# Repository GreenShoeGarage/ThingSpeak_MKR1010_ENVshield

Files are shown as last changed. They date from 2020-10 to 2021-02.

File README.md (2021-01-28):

View this project on [CADLAB.io](https://cadlab.io/project/23807). 

# Workspace Health Monitoring Gadget

[https://greenshoegarage.com/2020/10/learning-from-covid-19/](https://greenshoegarage.com/2020/10/learning-from-covid-19/)

## Goal

An open-source device that can monitor 8+ key environmental factors that affect people's perception of a healthy and productive workspace:

* Temperature
* Pressure
* eCO2
* Humidity
* Brightness
* Noise
* TVOC
* PM 2.5um

### Code and hardware is a prototype, no guarentee of any sort is implied. Use at your own risk.

## Functionality

1. Monitor 8 environmental factors
   1. Central processing of all sensor data
2. Record the telemetry locally
   1. 24-hour rolling log
   2. Store on microSD card
3. Display the telemetry locally
   1. Display new data point every 3 seconds
4. Transmit telemetry to web-based cloud service
   1. Send latest sensor readings every 10 minutes

## Bill of Materials

| Supplier | Product ID | Quantity | Description | Unit Price | Function | 
| :--- | :--- | :--- | :--- | :--- | :--- |
| Mouser | 782-ABX00023 | 1 | MKR1010 | $32.10 | Processing and Comms | 
| Mouser | 782-ASX00011 | 1 | MKR ENV Shield | $34.40 | Temp, UVA/UVB/UV Index, Humidity, Pressure, Lux |
| Adafruit | 3709 | 1 | SGP30 Air Quality Sensor Breakout | $19.95 | VOC, eCO2 | 
| Adafruit | 4632 | 1 | PMSA003I Air Quality Breakout | $44.95 | Particulate Matter | 
| Adafruit | 421 | 1 | I2S MEMS Microphone Breakout SPH0645LM4H | $6.95 | Noise | 

Get the PCB from OSHPark: [https://oshpark.com/shared\_projects/NU4I8Xzd](https://oshpark.com/shared_projects/NU4I8Xzd)

PartsBox Project BOM: [https://partsbox.com/mbparks/project/1s51nh9teghyx9e4by3gwn3nxp/](https://partsbox.com/mbparks/project/1s51nh9teghyx9e4by3gwn3nxp/)

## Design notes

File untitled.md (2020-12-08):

# Workspace Health Monitoring Gadget Wiki

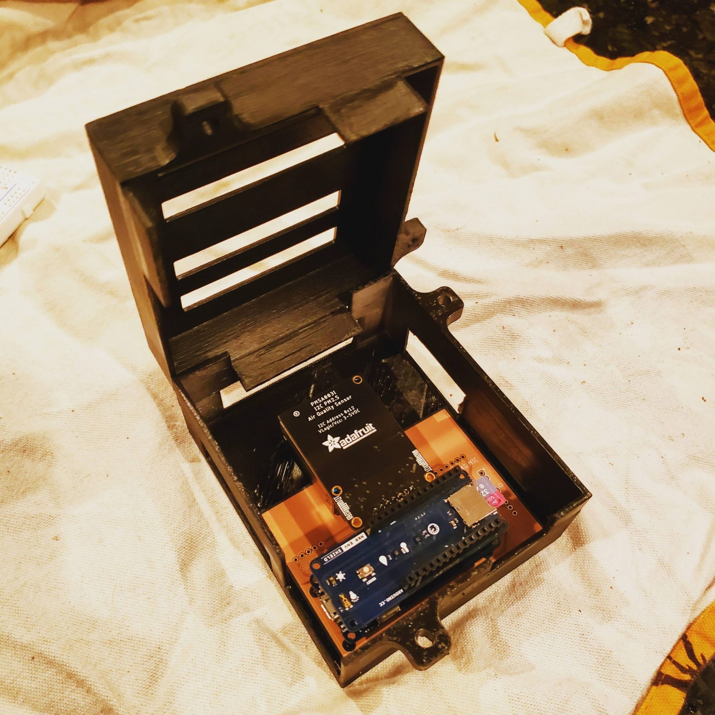
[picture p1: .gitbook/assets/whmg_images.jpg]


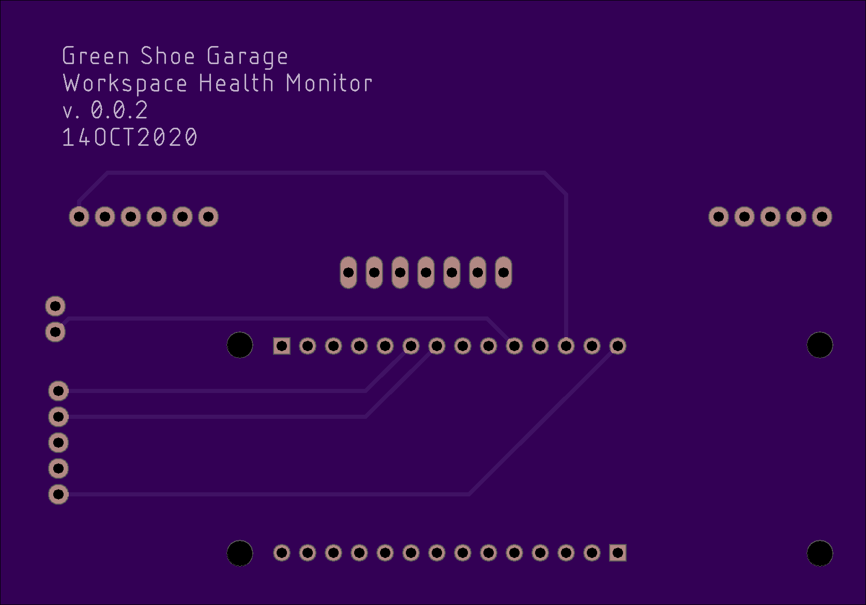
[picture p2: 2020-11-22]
Documentation/Images/OSHPark_PCB_Bottom.png

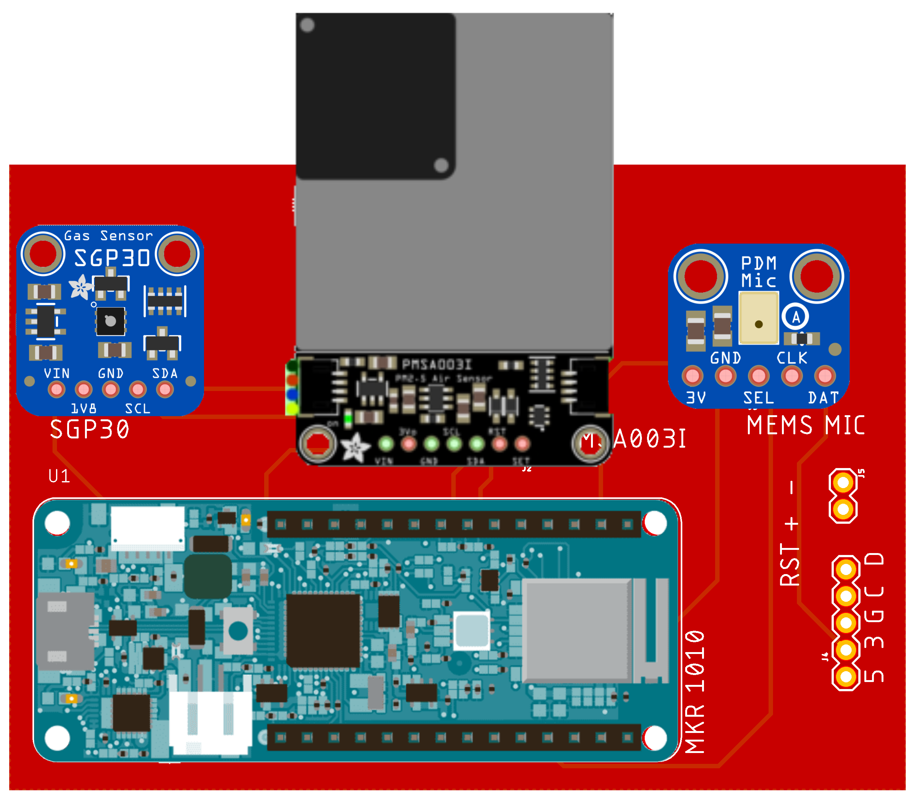
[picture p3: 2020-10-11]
Documentation/Images/WorkspaceHealthMonitor_v002_PCBA.png

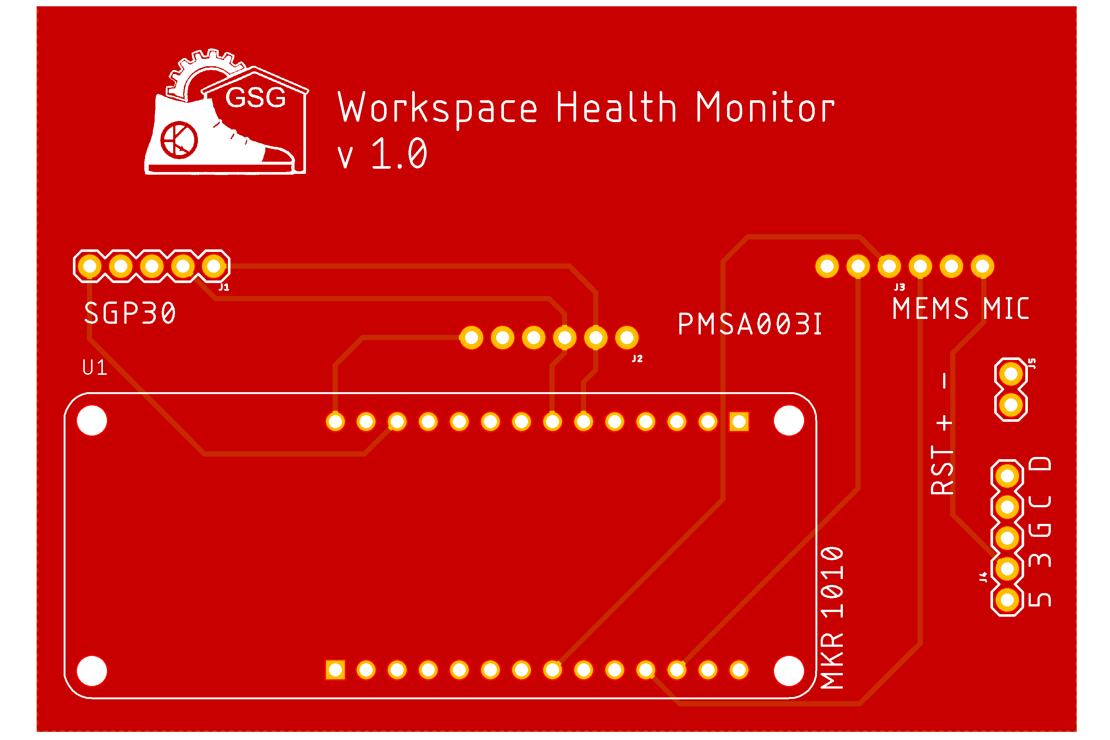
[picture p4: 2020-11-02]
Documentation/Images/WorkspaceHealthMonitor_v001_PCB.png

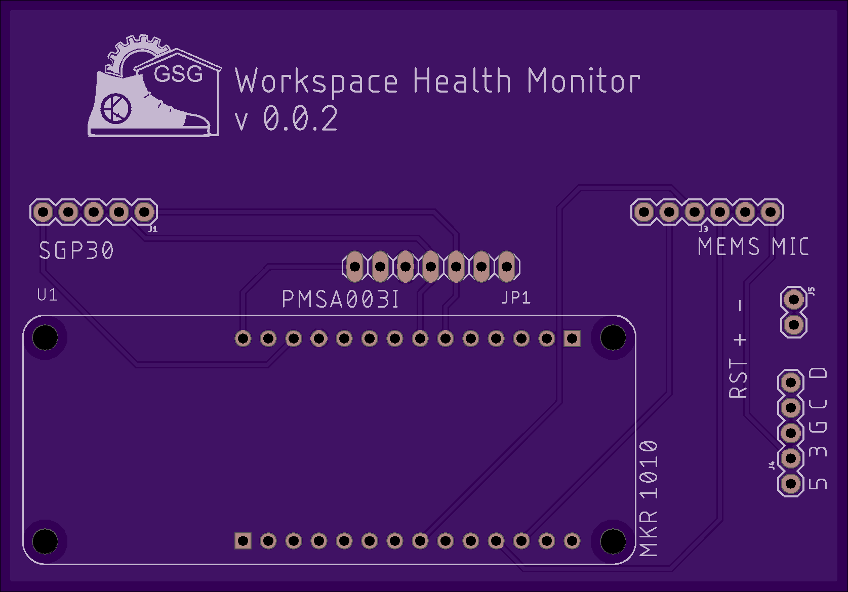
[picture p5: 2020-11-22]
Documentation/Images/OSHPark_PCB_Top.png

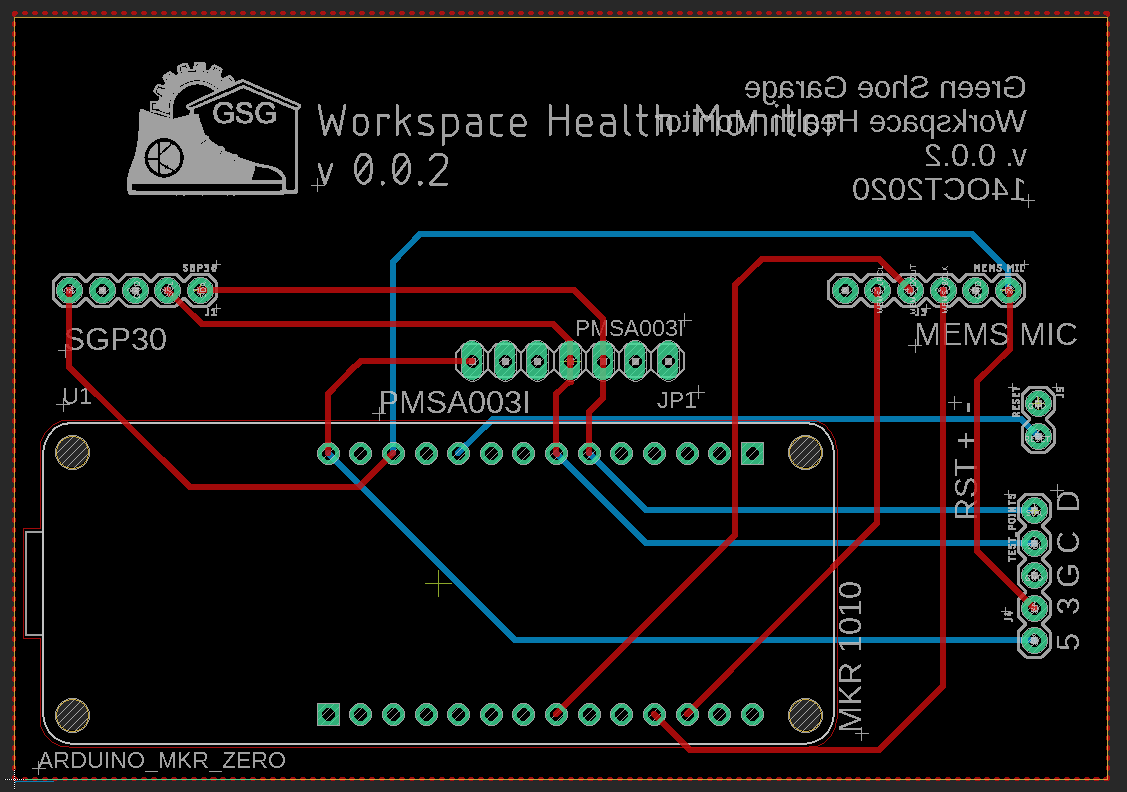
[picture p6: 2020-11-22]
Documentation/Images/WorkspaceHealthMonitor_BRD.png

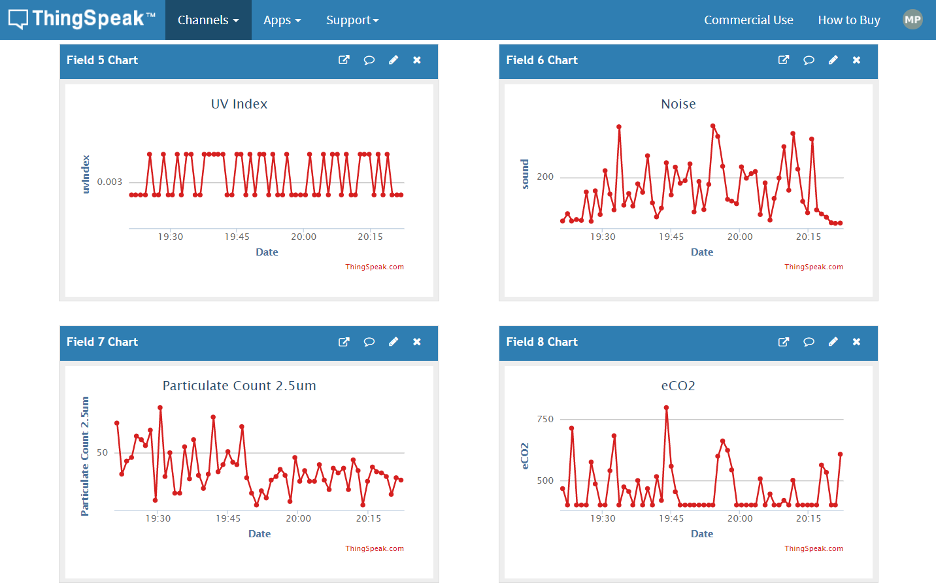
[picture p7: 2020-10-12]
Documentation/Images/ThingSpeak_Metrics02.png

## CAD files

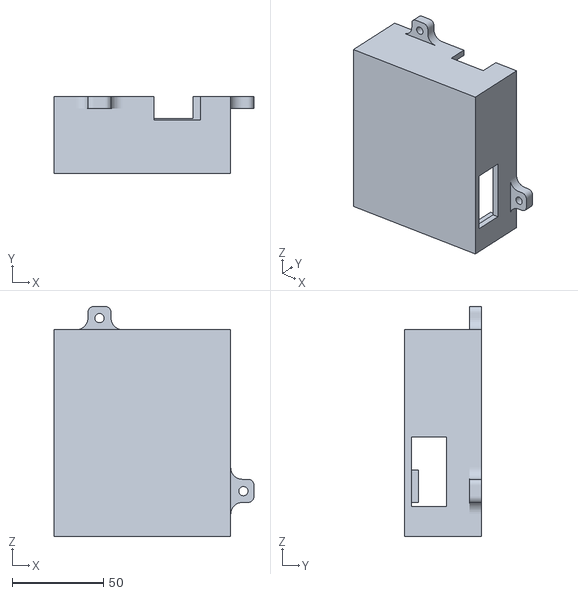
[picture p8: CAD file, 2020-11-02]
3D/Bottom_ThickWalls.stl
109.5 x 41.9 x 126.0

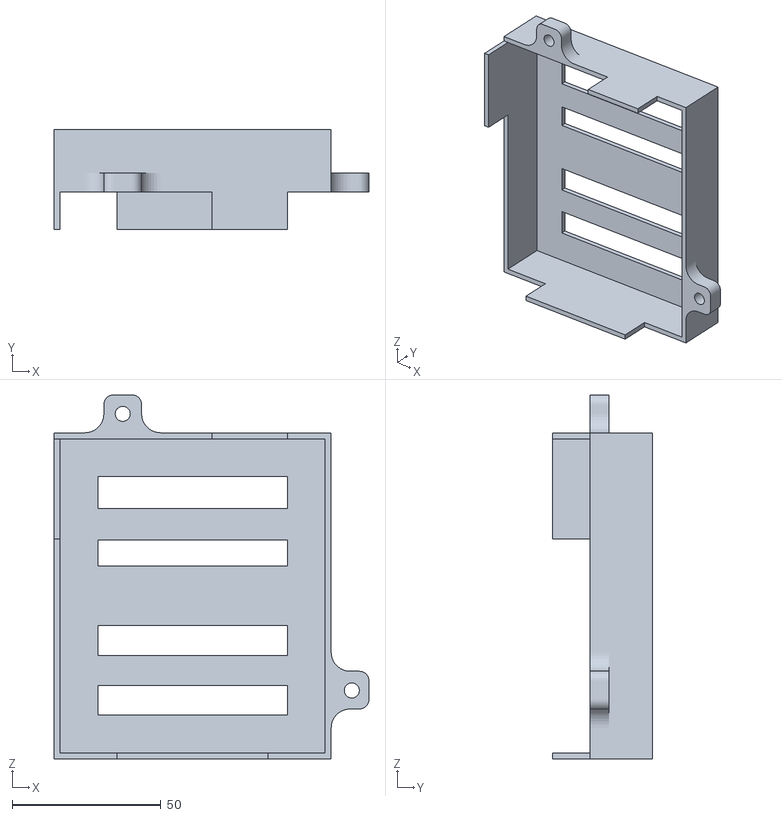
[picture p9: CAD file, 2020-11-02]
3D/Top.stl
105.9 x 33.8 x 122.4

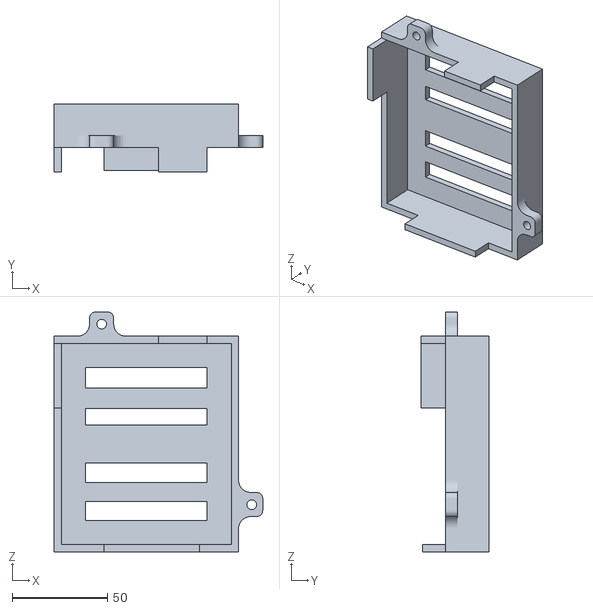
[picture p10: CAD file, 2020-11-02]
3D/Top_ThickWalls.stl
109.5 x 35.6 x 126.0

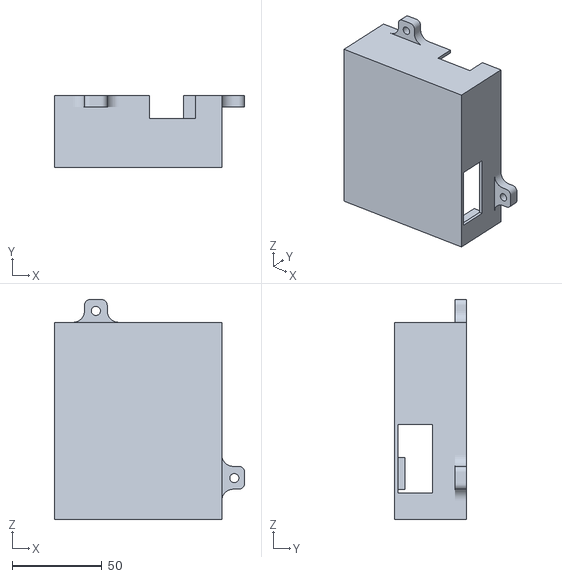
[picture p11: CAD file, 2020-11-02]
3D/Bottom.stl
105.9 x 40.1 x 122.4

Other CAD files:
3D/Bottom.obj
3D/Top.obj

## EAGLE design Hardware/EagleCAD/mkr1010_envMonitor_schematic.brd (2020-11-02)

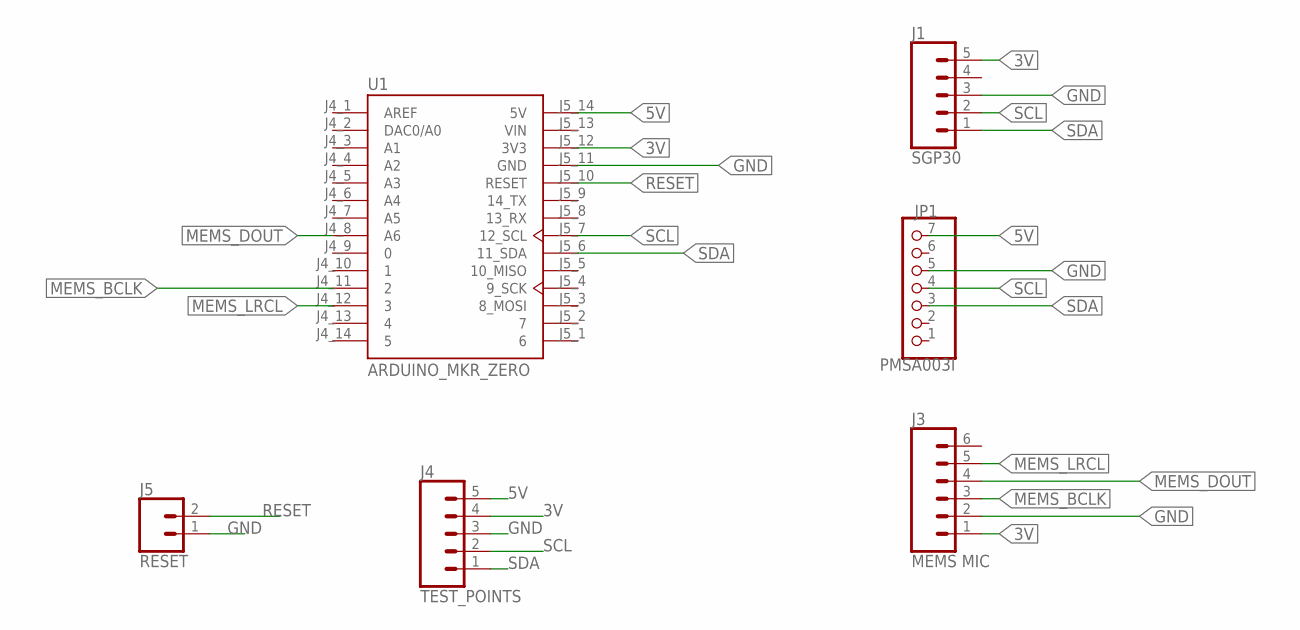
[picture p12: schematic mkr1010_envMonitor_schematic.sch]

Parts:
J1: SGP30; 1X05
J3: MEMS MIC; 1X06
J4: TEST_POINTS; 1X05
J5: RESET; 1X02
JP1: PMSA003I; 1X07
U1: ARDUINO_MKR_ZERO; MODULE_ARDUINO_MKR_ZERO

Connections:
3V: J1.5, J3.1, J4.4, U1.J5_12 (3V3)
5V: J4.5, JP1.7, U1.J5_14 (5V)
GND: J1.3, J3.2, J4.3, J5.1, JP1.5, U1.J5_11 (GND)
MEMS_BCLK: J3.3, U1.J4_11 (2)
MEMS_DOUT: J3.4, U1.J4_8 (A6)
MEMS_LRCL: J3.5, U1.J4_12 (3)
RESET: J5.2, U1.J5_10 (RESET)
SCL: J1.2, J4.2, JP1.4, U1.J5_7 (12_SCL)
SDA: J1.1, J4.1, JP1.3, U1.J5_6 (11_SDA)
VIN: U1.J5_13 (VIN)

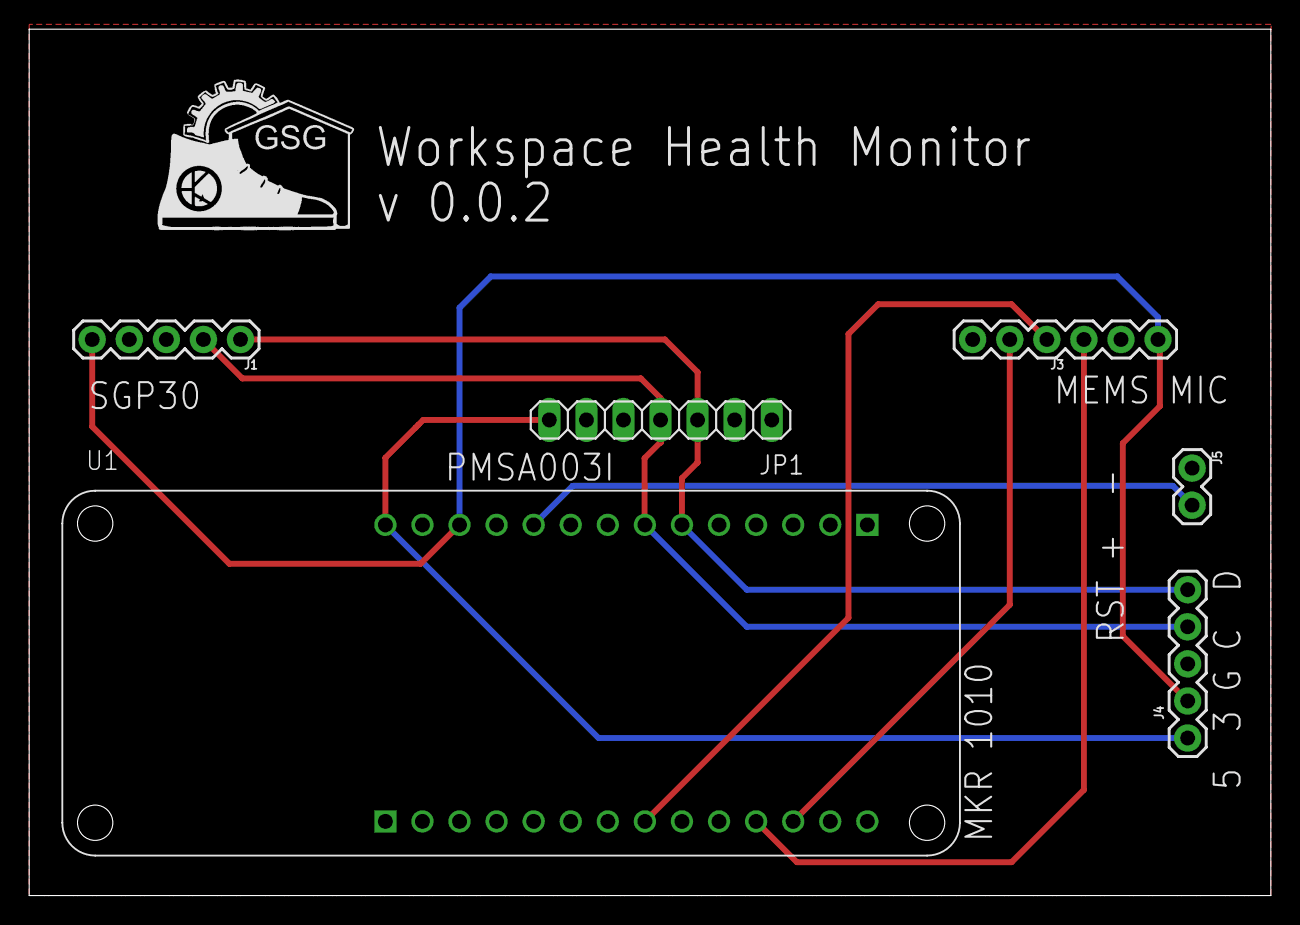
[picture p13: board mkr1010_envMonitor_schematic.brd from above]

Board: 2 copper layers, 85.1 x 59.4 mm, 6 parts (0 on the bottom side), 9 nets.

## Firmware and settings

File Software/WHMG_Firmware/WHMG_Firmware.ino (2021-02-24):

/*
  WriteMultipleFields

  Description: Writes values to fields 1,2,3,4 and status in a single ThingSpeak update every 20 seconds.

  Hardware: Arduino MKR WiFi 1010

  !!! IMPORTANT - Modify the secrets.h file for this project with your network connection and ThingSpeak channel details. !!!

  Note:
  - Requires WiFiNINA library
  - This example is written for a network using WPA encryption. For WEP or WPA, change the WiFi.begin() call accordingly.

  ThingSpeak ( https://www.thingspeak.com ) is an analytic IoT platform service that allows you to aggregate, visualize, and
  analyze live data streams in the cloud. Visit https://www.thingspeak.com to sign up for a free account and create a channel.

  Documentation for the ThingSpeak Communication Library for Arduino is in the README.md folder where the library was installed.
  See https://www.mathworks.com/help/thingspeak/index.html for the full ThingSpeak documentation.

  For licensing information, see the accompanying license file.

  Copyright 2018, The MathWorks, Inc.

  Microphone Connections (Adafruit I2S MEMS Microphone Breakout SPH0645LM4H)
    GND connected GND
    3.3V connected 3.3V (Feather, Zero) or VCC (MKR1000, MKRZero)
    LRCLK / WS connected to pin 0 (Feather, Zero) or pin 3 (MKR1000, MKRZero)
    BCLK connected to pin 1 (Feather, Zero) or pin 2 (MKR1000, MKRZero)
    DOUT connected to pin 9 (Zero) or pin A6 (MKR1000, MKRZero
    SEL N/C

  Adafruit PM2.5 sensor (MSA003I Air Quality Breakout (PM0.3-100um))
    I2C address 0x12 (cannot be changed)
    3.3V
    SDA, SCL, 3V, GND

  SGP30 Air Quality Sensor Breakout (TVOC and eCO2)
    The sensor uses I2C address 0x58
    Since the sensor chip uses 3 VDC for logic, we have included a voltage regulator on board that will take 3-5VDC and safely convert it down
    SDA, SCL, 3.3V or 5V, GND

*/

#include <SPI.h>
#include <SD.h>
#include <WiFiNINA.h>
#include <Arduino_MKRENV.h>
#include <I2S.h>
#include <ArduinoLowPower.h>
#include "ThingSpeak.h"
#include "secrets.h"
#include "Adafruit_PM25AQI.h"
#include <utility/wifi_drv.h>
#include "Adafruit_SGP30.h"



#define SAMPLES 128
#define CSPIN 4
#define GREEN_LED 25
#define RED_LED 26
#define BLUE_LED 27


float sensor_temperature_reading = 0.0;
float sensor_humidity_reading    = 0.0;
float sensor_pressure_reading    = 0.0;
float sensor_illuminance_reading = 0.0;
float sensor_uva_reading         = 0.0;
float sensor_uvb_reading         = 0.0;
float sensor_uvIndex_reading     = 0.0;
float sensor_noiseLevel_reading  = 0.0;

int sensor_partcount_03um_reading  = 0;
int sensor_partcount_05um_reading  = 0;
int sensor_partcount_10um_reading  = 0;
int sensor_partcount_25um_reading  = 0;
int sensor_partcount_50um_reading  = 0;
int sensor_partcount_100um_reading = 0;

uint16_t sensor_tvoc_reading = 0;
uint16_t sensor_eco2_reading = 0;

Adafruit_PM25AQI aqi = Adafruit_PM25AQI();
PM25_AQI_Data aqiData;

Adafruit_SGP30 sgp;

unsigned long lastSDWriteTime = 0;
const unsigned long SDwriteDelay = 5000;

unsigned long lastTransmitTime = 0;
const unsigned long transmitDelay = 5000;

char ssid[] = SECRET_SSID;   // your network SSID (name)
char pass[] = SECRET_PASS;   // your network password
WiFiClient  client;

unsigned long myChannelNumber = SECRET_CH_ID;
const char * myWriteAPIKey = SECRET_WRITE_APIKEY;

const char* FILENAME = "telemetr.csv";
File myFile;






//////////////////////////////////////////////////////////////////////////
void setup() {
  WiFiDrv::pinMode(GREEN_LED, OUTPUT);  //GREEN
  WiFiDrv::pinMode(RED_LED, OUTPUT);  //RED
  WiFiDrv::pinMode(BLUE_LED, OUTPUT);  //BLUE
  WiFiDrv::digitalWrite(GREEN_LED, HIGH); // for full brightness
  WiFiDrv::digitalWrite(RED_LED, LOW); // for full brightness
  WiFiDrv::digitalWrite(BLUE_LED, LOW); // for full brightness

  Serial.begin(115200);  // Initialize serial
  while (!Serial) {
    blinkLedError();
  }

  Serial.print("Initializing MKR ENV shield...");
  if (!ENV.begin()) {
    Serial.println("FAILED to initialize MKR ENV shield!");
    while (true) {
      blinkLedError();
    }
  }
  Serial.println("MKR ENV shield successfully initialized");


  Serial.print("Initializing I2S microphone...");
  if (!I2S.begin(I2S_PHILIPS_MODE, 16000, 32)) {
    Serial.println("FAILED to initialize I2S microphone!");
    while (true) {
      blinkLedError();
    }
  }
  Serial.println("I2S microphone successfully initialized");


  Serial.print("Initializing PM 2.5 AQI Sensor...");
  if (! aqi.begin_I2C()) {      // connect to the sensor over I2C
    Serial.println("Could not find PM 2.5 sensor!");
    while (true) {
      blinkLedError();
    }
  }
  Serial.println("PM 2.5 AQI sensor successfully initialized!");


  Serial.print("Initializing SGP30 sensor...");
  if (! sgp.begin()) {
    Serial.println("Sensor not found :(");
    while (1);
  }
  Serial.println("SGP30 sensor successfully initialized!");


  Serial.print("Initializing WiFi module...");
  if (WiFi.status() == WL_NO_MODULE) {
    Serial.println("Communication with WiFi module failed!");
    while (true) {
      blinkLedError();
    }
  }
  String fv = WiFi.firmwareVersion();
  Serial.print("Wifi Firmware Version: ");
  Serial.println(fv);
  Serial.println("WiFi successfully initialized");


  Serial.print("Initializing SD card...");
  if (!SD.begin(CSPIN))
  {
    Serial.println("initialization failed!");
    while (true) {
      blinkLedError();
    }
  }
  Serial.println("SD card successfully initialized.");

  ThingSpeak.begin(client);  //Initialize ThingSpeak
}




///////////////////////////////////////////////////////////////////////////////////////////////
void loop() {
  readSensors();
  printTelemetry();
  sendToThingspeak();
  writeTelemetrySD();
  delay(2000);
}




///////////////////////////////////////////////////////////////////////////////////////////////
void readSensors() {
  readMKR();
  readNoiseSensor();
  readAQI();
  readSGP();
}



///////////////////////////////////////////////////////////////////////////////////////////////
void readMKR() {
  sensor_temperature_reading = ENV.readTemperature();
  sensor_humidity_reading    = ENV.readHumidity();
  sensor_pressure_reading    = ENV.readPressure();
  sensor_illuminance_reading = ENV.readIlluminance();
  sensor_uva_reading         = ENV.readUVA();
  sensor_uvb_reading         = ENV.readUVB();
  sensor_uvIndex_reading     = ENV.readUVIndex();
}




///////////////////////////////////////////////////////////////////////////////////////////////
void readNoiseSensor() {
  int samples[SAMPLES];

  for (int i = 0; i < SAMPLES; i++) {
    int sample = 0;
    while ((sample == 0) || (sample == -1) ) {
      sample = I2S.read();
    }
    // convert to 18 bit signed
    sample >>= 14;
    samples[i] = sample;
  }

  // ok we hvae the samples, get the mean (avg)
  float meanval = 0;
  for (int i = 0; i < SAMPLES; i++) {
    meanval += samples[i];
  }
  meanval /= SAMPLES;

  // subtract it from all sapmles to get a 'normalized' output
  for (int i = 0; i < SAMPLES; i++) {
    samples[i] -= meanval;
  }

  // find the 'peak to peak' max
  float maxsample, minsample;
  minsample = 100000;
  maxsample = -100000;
  for (int i = 0; i < SAMPLES; i++) {
    minsample = min(minsample, samples[i]);
    maxsample = max(maxsample, samples[i]);
  }
  sensor_noiseLevel_reading = maxsample - minsample;
}





///////////////////////////////////////////////////////////////////////////////////////////////
void readAQI() {
  if (! aqi.read(&aqiData)) {
    Serial.println("Could not read from AQI");
    delay(500);  // try again in a bit!
    return;
  }
  //Serial.println("AQI reading success");

  sensor_partcount_03um_reading = aqiData.particles_03um;
  sensor_partcount_05um_reading = aqiData.particles_05um;
  sensor_partcount_10um_reading = aqiData.particles_10um;
  sensor_partcount_25um_reading = aqiData.particles_25um;
  sensor_partcount_50um_reading = aqiData.particles_50um;
  sensor_partcount_100um_reading = aqiData.particles_100um;
}





///////////////////////////////////////////////////////////////////////////////////////////////
void readSGP() {
  static int counter = 0;

  if (! sgp.IAQmeasure()) {
    Serial.println("Measurement failed");
    return;
  }
  //Serial.print("TVOC "); Serial.print(sgp.TVOC); Serial.print(" ppb\t");
  //Serial.print("eCO2 "); Serial.print(sgp.eCO2); Serial.println(" ppm");

  if (! sgp.IAQmeasureRaw()) {
    Serial.println("Raw Measurement failed");
    return;
  }
  //Serial.print("Raw H2 "); Serial.print(sgp.rawH2); Serial.print(" \t");
  //Serial.print("Raw Ethanol "); Serial.print(sgp.rawEthanol); Serial.println("");

  delay(1000);

  counter++;
  if (counter == 30) {
    counter = 0;

    uint16_t TVOC_base, eCO2_base;
    if (! sgp.getIAQBaseline(&eCO2_base, &TVOC_base)) {
      Serial.println("Failed to get baseline readings");
      return;
    }
    //Serial.print("****Baseline values: eCO2: 0x"); Serial.print(eCO2_base, HEX);
    //Serial.print(" & TVOC: 0x"); Serial.println(TVOC_base, HEX);
  }

  sensor_tvoc_reading = sgp.TVOC;
  sensor_eco2_reading = sgp.eCO2;

}




///////////////////////////////////////////////////////////////////////////////////////////////
void printTelemetry() {
  Serial.println(F("------------------------------------------------------------"));
  Serial.print(F("Time (ms) since last reboot: "));
  Serial.println(millis());
  Serial.println();

  Serial.print(F(">> Environmental Conditions: "));
  Serial.println();
  Serial.print(F("Temperature (C): "));
  Serial.println(sensor_temperature_reading);
  Serial.print(F("Humidity (%): "));
  Serial.println(sensor_humidity_reading);
  Serial.print(F("Atmosphere Pressure (kPa): "));
  Serial.println(sensor_pressure_reading);
  Serial.print(F("Illuminance (Lux): "));
  Serial.println(sensor_illuminance_reading);
  Serial.print(F("UVA: "));
  Serial.println(sensor_uva_reading);
  Serial.print(F("UVB: "));
  Serial.println(sensor_uvb_reading);
  Serial.print(F("UV Index: "));
  Serial.println(sensor_uvIndex_reading);
  Serial.println();

  Serial.print(F(">> Noise Level: "));
  Serial.println(sensor_noiseLevel_reading);
  Serial.println();

  Serial.println(F(">> Air Quality: Particulate Matter"));
  Serial.println(F("Concentration Units (standard)"));
  Serial.print(F("PM 1.0: ")); Serial.print(aqiData.pm10_standard);
  Serial.print(F("\t\tPM 2.5: ")); Serial.print(aqiData.pm25_standard);
  Serial.print(F("\t\tPM 10: ")); Serial.println(aqiData.pm100_standard);
  Serial.println(F("-----"));
  Serial.println(F("Concentration Units (environmental)"));
  Serial.print(F("PM 1.0: ")); Serial.print(aqiData.pm10_env);
  Serial.print(F("\t\tPM 2.5: ")); Serial.print(aqiData.pm25_env);
  Serial.print(F("\t\tPM 10: ")); Serial.println(aqiData.pm100_env);
  Serial.println(F("-----"));
  Serial.print(F("Particles > 0.3um / 0.1L air:")); Serial.println(sensor_partcount_03um_reading);
  Serial.print(F("Particles > 0.5um / 0.1L air:")); Serial.println(sensor_partcount_05um_reading);
  Serial.print(F("Particles > 1.0um / 0.1L air:")); Serial.println(sensor_partcount_10um_reading);
  Serial.print(F("Particles > 2.5um / 0.1L air:")); Serial.println(sensor_partcount_25um_reading);
  Serial.print(F("Particles > 5.0um / 0.1L air:")); Serial.println(sensor_partcount_50um_reading);
  Serial.print(F("Particles > 50 um / 0.1L air:")); Serial.println(sensor_partcount_100um_reading);
  Serial.println();

  Serial.println(F(">> Air Quality: eCO2 and TVOC"));
  Serial.print(F("eCO2: "));
  Serial.println(sensor_eco2_reading);
  Serial.print(F("TVOC: "));
  Serial.println(sensor_tvoc_reading);
  Serial.println();
  Serial.println(F("------------------------------------------------------------"));

  for (int x = 0; x < 3; x++) {
    Serial.println();
  }

}



///////////////////////////////////////////////////////////////////////////////////////////////
void sendToThingspeak() {
  // Connect or reconnect to WiFi
  if ((millis() - lastTransmitTime) > transmitDelay) {
    if (WiFi.status() != WL_CONNECTED) {
      Serial.print("Attempting to connect to SSID: ");
      Serial.println(SECRET_SSID);
      while (WiFi.status() != WL_CONNECTED) {
        WiFi.begin(ssid, pass); // Connect to WPA/WPA2 network. Change this line if using open or WEP network
        Serial.print(".");
        delay(5000);
      }
      Serial.println("\nConnected.");
    }

    // set the fields with the values
    ThingSpeak.setField(1, sensor_temperature_reading);
    ThingSpeak.setField(2, sensor_humidity_reading);
    ThingSpeak.setField(3, sensor_pressure_reading);
    ThingSpeak.setField(4, sensor_illuminance_reading);
    ThingSpeak.setField(5, sensor_tvoc_reading);
    ThingSpeak.setField(6, sensor_noiseLevel_reading);
    ThingSpeak.setField(7, sensor_partcount_25um_reading);
    ThingSpeak.setField(8, sensor_eco2_reading);

    // write to the ThingSpeak channel
    int x = ThingSpeak.writeFields(myChannelNumber, myWriteAPIKey);
    if (x == 200) {
      Serial.println("Telemetry upload to ThingSpeak successful.");
    }
    else {
      Serial.println("Problem updating channel. HTTP error code " + String(x));
    }
    lastTransmitTime = millis();
  }
}








///////////////////////////////////////////////////////////////////////////////////////////////
void writeTelemetrySD() {
  noInterrupts();
  if ((millis() - lastSDWriteTime) > SDwriteDelay) {
    myFile = SD.open(FILENAME, FILE_WRITE);
    if (myFile)
    {
      myFile.print(sensor_temperature_reading);
      myFile.print(",");
      myFile.print(sensor_humidity_reading);
      myFile.print(",");
      myFile.print(sensor_pressure_reading);
      myFile.print(",");
      myFile.print(sensor_illuminance_reading);
      myFile.print(",");
      myFile.print(sensor_uva_reading);
      myFile.print(",");
      myFile.print(sensor_uvb_reading);
      myFile.print(",");
      myFile.print(sensor_uvIndex_reading);
      myFile.print(",");
      myFile.println(sensor_noiseLevel_reading);
      myFile.print(",");
      myFile.println(sensor_partcount_03um_reading);
      myFile.print(",");
      myFile.println(sensor_partcount_05um_reading);
      myFile.print(",");
      myFile.println(sensor_partcount_10um_reading);
      myFile.print(",");
      myFile.println(sensor_partcount_25um_reading);
      myFile.print(",");
      myFile.println(sensor_partcount_50um_reading);
      myFile.print(",");
      myFile.println(sensor_partcount_100um_reading);
      myFile.print(",");
      myFile.println(sensor_eco2_reading);
      myFile.print(",");
      myFile.println(sensor_tvoc_reading);
      myFile.close();

      Serial.println("Telemetry write to SD card is successful.");
      lastSDWriteTime = millis();
    }
    else {
      Serial.print("WARNING! SD Card problem. Error opening file: ");
      Serial.println(FILENAME);
    }


  }
  interrupts();
}







///////////////////////////////////////////////////////////////////////////////////////////////
void blinkLedError() {
  WiFiDrv::digitalWrite(GREEN_LED, LOW); // for full brightness
  WiFiDrv::digitalWrite(RED_LED, LOW); // for full brightness
  WiFiDrv::digitalWrite(BLUE_LED, HIGH); // for full brightness
  delay(1000);
  WiFiDrv::digitalWrite(GREEN_LED, LOW); // for full brightness
  WiFiDrv::digitalWrite(RED_LED, HIGH); // for full brightness
  WiFiDrv::digitalWrite(BLUE_LED, LOW); // for full brightness
  delay(1000);
}

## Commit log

2020-07-21 Corrected for MKR1010 LEDs
2020-07-29 added support for SGP30 sensor (eCO2 and TVOC)
2020-10-11 init hardware (board/schematic) commit
    [mkr1010_envMonitor_schematic.brd, mkr1010_envMonitor_schematic.sch]
2020-11-02 Corrected PMSA003I board layout (6pin vs 7pin header)
    [mkr1010_envMonitor_schematic.brd, mkr1010_envMonitor_schematic.sch]
2020-11-02 PCB images
2020-11-02 Thicker walls for enclosure
    [Bottom.obj, Bottom.stl, Bottom_ThickWalls.stl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]
2020-11-22 updated doc with v0.0.2 PCB
2020-11-22 new CAM files for PCB v0.0.2

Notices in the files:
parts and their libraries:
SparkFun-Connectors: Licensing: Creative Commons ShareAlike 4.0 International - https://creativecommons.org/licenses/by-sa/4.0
